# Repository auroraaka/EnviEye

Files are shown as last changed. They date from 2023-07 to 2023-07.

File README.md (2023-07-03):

# EnviEye: Air Pollution Monitoring System
A novel, cost-effective, and temperature/humidity drift resilient air pollution monitor for detecting CO2, CO, CH4, NOx, NH3, H2S, and VOCs. Building an open-source database of minute-by-minute air quality in high-risk locations across Massachusetts. In partnership with the MassDEP and sponsored by EPA Enhanced Air Quality Monitoring for Communities Grant.

## Quick Links
- [Sensor Map Database](https://www.environa.org/envieye): location marker database of ThingSpeak channels displaying active data from live EnviEye air pollution monitors
- [Build Guide](https://docs.google.com/presentation/d/e/2PACX-1vTb9qzZoU7ihO3saF2nRVf8Kc_sK2KtpKpaAT560-QxsJg3QxZHz59rv6SrPiSbV5mgcdfRNgG8oTTH/pub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): step-by-step instructional manual slideshow including required components and tools
- [Technical Documentation](https://www.environa.org/_files/ugd/a23aa6_806df408c55a414ab66d8ea2d8b6d26c.pdf): full engineering-based analysis of sensor theory, technology, limitations, and impact
- [IEEE Sensors Paper](https://ieeexplore.ieee.org/document/9812483): discusses how to improve the accuracy of MOS gas sensors in ambient conditions
- [Patent](https://patents.google.com/patent/US20230112016A1/en): establishes intellectual property over sensor innovations

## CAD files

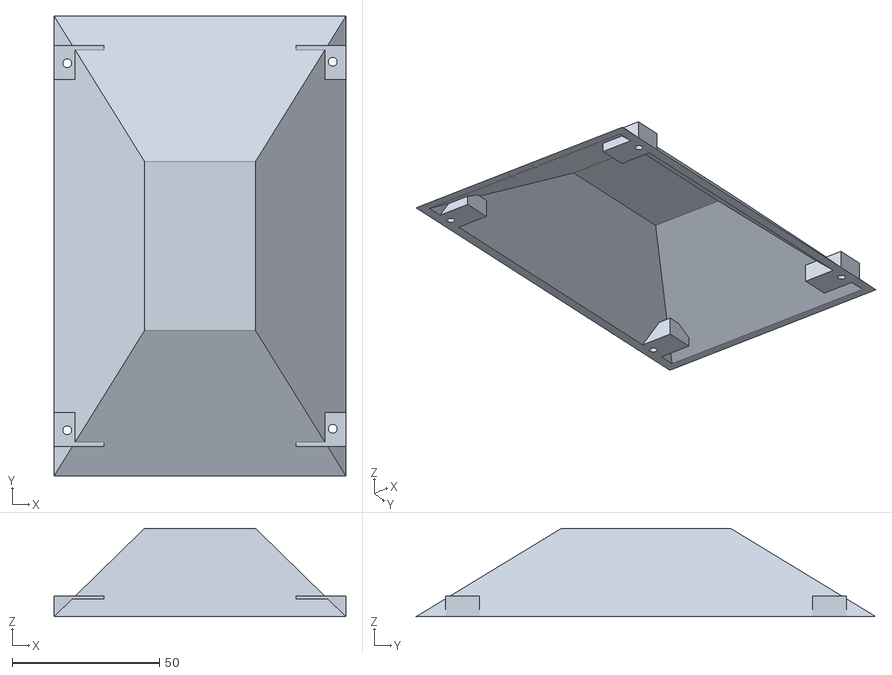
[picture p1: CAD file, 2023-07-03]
Hardware/Enclosure/Roof.obj
99.0 x 156.0 x 30.0

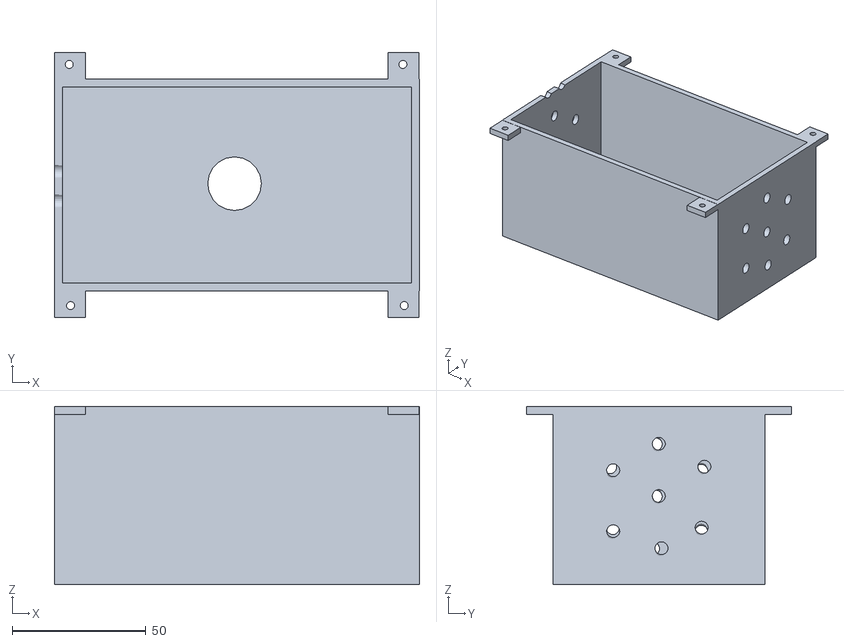
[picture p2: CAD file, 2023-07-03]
Hardware/Enclosure/Base.obj
136.2 x 99.0 x 66.5

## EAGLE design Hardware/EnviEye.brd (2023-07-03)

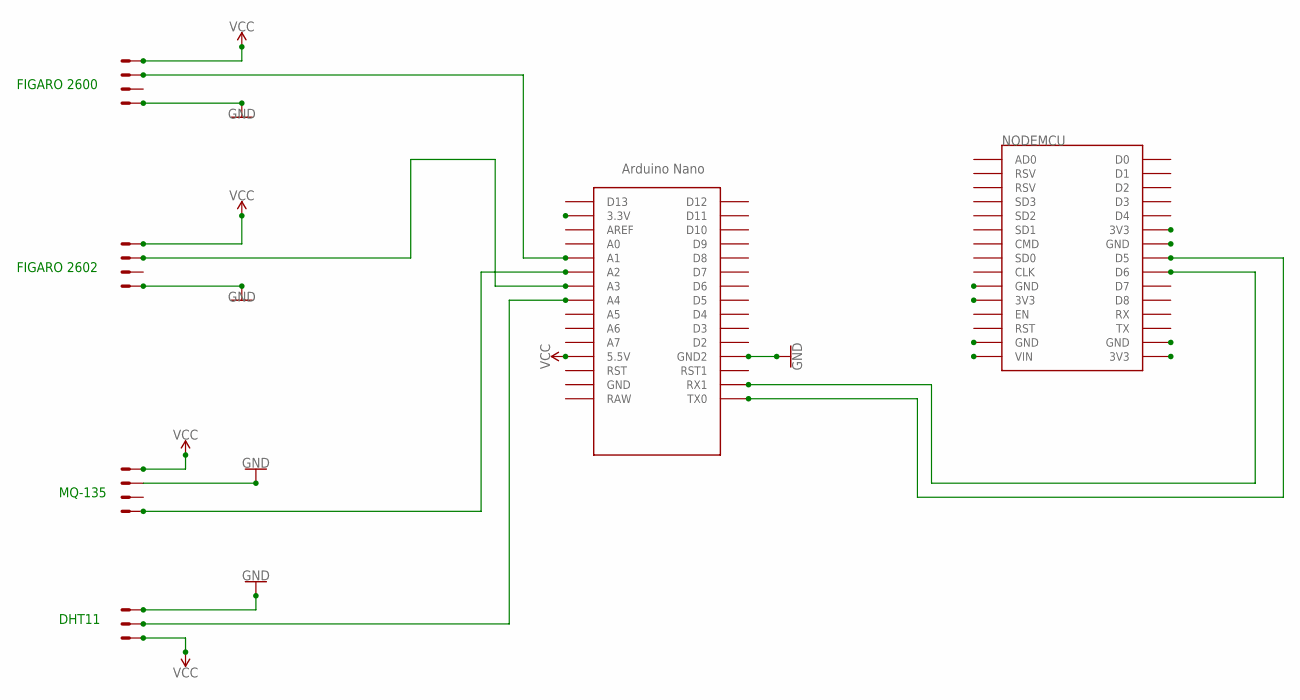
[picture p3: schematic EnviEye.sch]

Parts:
DHT11: 22-23-2031
FIGARO2600, FIGARO2602: 22-23-2041
MQ-135: 22-23-2041
NODEMCU: ESP12E_DEVKIT
U$1: NANO

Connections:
GND: DHT11.3, FIGARO2600.4, FIGARO2602.4, MQ-135.2, U$1.GND1 (GND2)
unnamed: FIGARO2600.2, U$1.A3
unnamed: FIGARO2602.2, U$1.A1
unnamed: NODEMCU.D6, U$1.RX1
unnamed: NODEMCU.D5, U$1.TX0
unnamed: DHT11.2, U$1.A4
unnamed: MQ-135.4, U$1.A2
VCC: DHT11.1, FIGARO2600.1, FIGARO2602.1, MQ-135.1, U$1.5V (5.5V)

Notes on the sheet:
MQ-135
DHT11
FIGARO 2602
FIGARO 2600

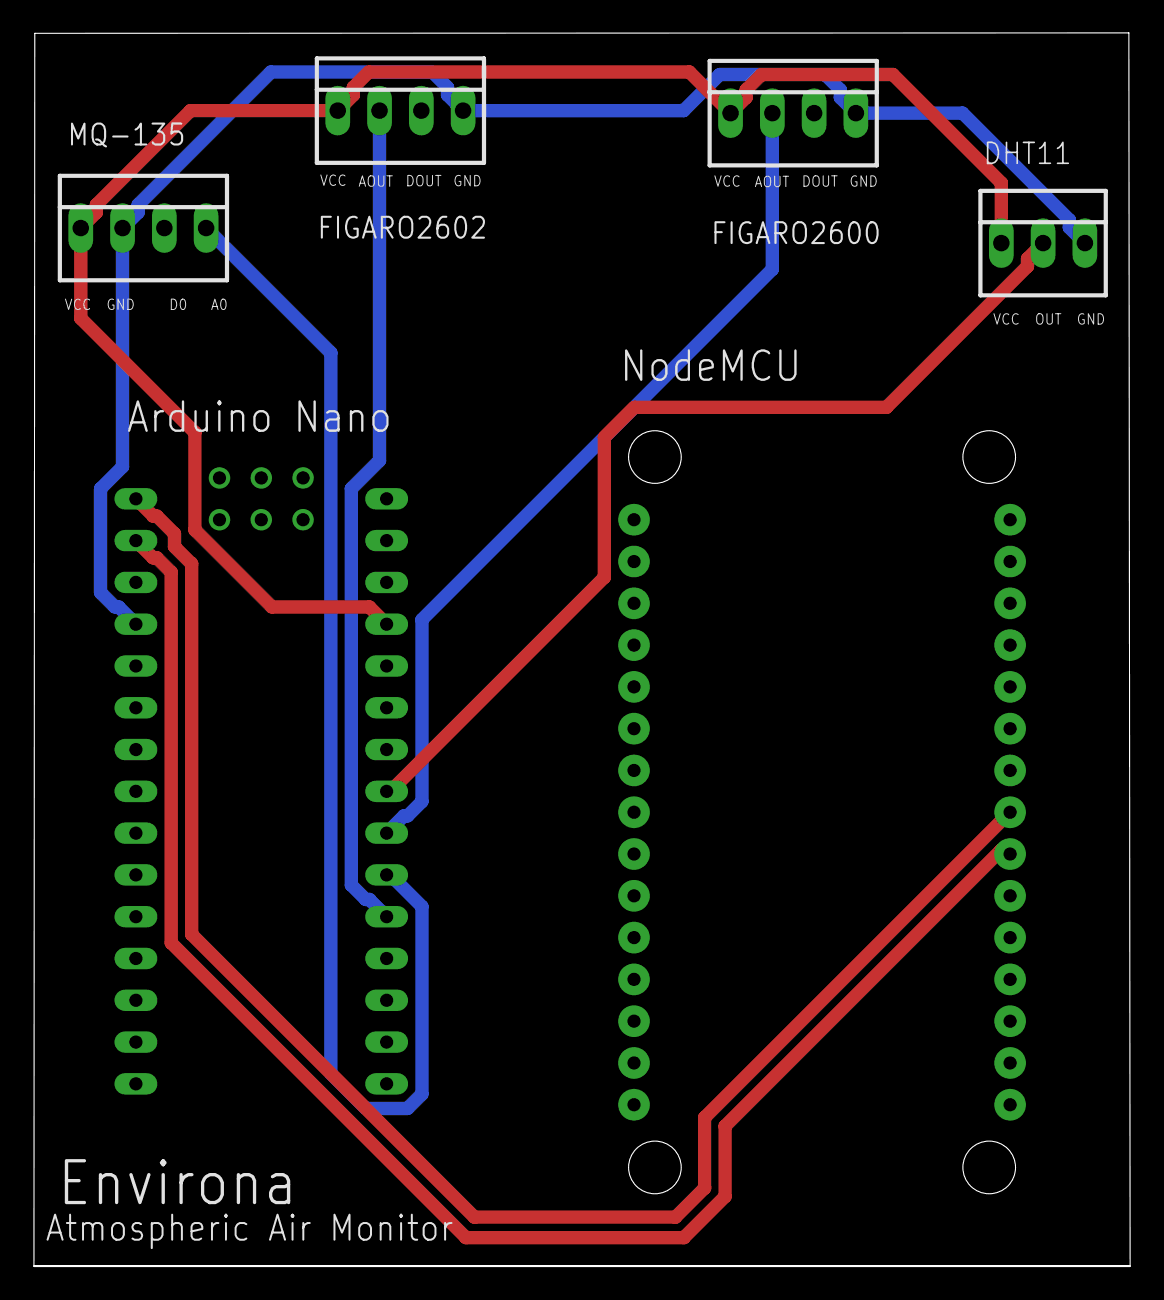
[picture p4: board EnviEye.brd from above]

Board: 2 copper layers, 66.6 x 75.0 mm, 6 parts (0 on the bottom side), 8 nets.

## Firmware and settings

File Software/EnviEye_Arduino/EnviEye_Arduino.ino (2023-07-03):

/* 
Atmospheric Air Analyzer
Environa
Akarsh Aurora
11/13/20
*/
 
#include <ArduinoJson.h>
#include <DHT.h>

// Gas Sensor Pins
#define F2600 A1
#define MQ135 A2
#define F2602 A3
#define DHTPIN A4
    
// 2600 Gases
float A_CO = 1.144997421;
float B_CO = -0.21687423;

float A_CH4 = 1.05777824;
float B_CH4 = -0.0795645;

// 2602 Gases
float A_NH3 = 0.92372844;
float B_NH3 = -0.291578925;

float A_H2S = 0.38881036;
float B_H2S = -0.35010059;

float A_VOC = 0.3220722;
float B_VOC = -0.6007520;

// MQ-135 Gases
float A_CO2 = 112.89808; 
float B_CO2 = -2.868463517;  

float A_NOx = 34.69756084;  
float B_NOx = -3.422829698; 

// DHT Temperature and Humidity
#define DHTTYPE DHT11
DHT dht(DHTPIN, DHTTYPE, 6);
float H, T, F;

void setup() {
  pinMode(13, OUTPUT);
  Serial.begin(9600);
  dht.begin();
}

void loop() {

  // Setting Pin 13 to GND
  digitalWrite(13, LOW);
  
  // DHT11 Temperature and Humidity Measurements
  DetectTemperatureHumidity ();
  
  // Figaro 2600 Gas Concentrations (CO and CH4)
  float ratio_F2600 = CalculateRatio(F2600, CalculateK_2600(), 400);
  float ppm_CO = A_CO * pow(ratio_F2600, B_CO) * 0.1;
  float ppm_CH4 = A_CH4 * pow(ratio_F2600, B_CH4) * 0.1;

  // MQ-135 Gas Concentrations (CO2 and NOx)
  float ratio_MQ135 = CalculateRatio(MQ135, CalculateK_MQ135(), 24);
  float ppm_CO2 = analogRead(MQ135) + 325;
  float ppm_NOx = A_NOx * pow(ratio_MQ135, B_NOx) * 10;

  // Figaro 2602 Gas Concentrations (VOC, H2S, and NH3)
  float ratio_F2602 = CalculateRatio(F2602, CalculateK_2602(), 225);
  float ppm_VOC = A_VOC * pow(ratio_F2602, B_VOC) * 0.001 * 1000000/2;
  float ppm_H2S = A_H2S * pow(ratio_F2602, B_H2S) * 0.001;
  float ppm_NH3 = A_NH3 * pow(ratio_F2602, B_NH3) * 0.001;  
  
  // Upload data to ThingSpeak Channel
  DynamicJsonBuffer jBuffer; 
  JsonObject& root = jBuffer.createObject();

  root["CO2"] = ppm_CO2;
  root["CO"] = ppm_CO;
  root["CH4"] = ppm_CH4;
  root["NOx"] = ppm_NOx;
  root["NH3"] = ppm_NH3;
  root["H2S"] = ppm_H2S;
  root["VOC"] = ppm_VOC;
  root["Temperature"] = T;
  root["Humidity"] = H;
   
  root.prettyPrintTo(Serial);
  Serial.println("");

  // ThingSpeak Delay
  delay(10000);
}

// Calculate Rs/Ro
float CalculateRatio (int SensorPin, float K, float Rs0){
  float VRL;
  float Rs;
  float RL = 10;
  float Ro;
  float ratio;
  VRL = analogRead(SensorPin)*(5.0/1023.0);
  Rs = (5.0/VRL - 1)*RL;
  Ro = Rs0/K;
  ratio = Rs/Ro;
  return ratio;
}


float CalculateK_2600 (){
  float K_2600;
  K_2600 = (-6.073E-7)*pow(T, 4) + (4.218E-5)*pow(T, 3) + (-8.710E-5)*pow(T, 2) + (-0.055)*T + (1.901);
  return K_2600;
}

float CalculateK_2602 (){
  float K_2602;
  K_2602 = (-1.519E-7)*pow(T, 4) + (1.796E-5)*pow(T, 3) + (-5.415E-4)*pow(T, 2) + (-0.024)*T + (1.585);
  return K_2602;
}

float CalculateK_MQ135 (){
  float K_MQ135;
  K_MQ135 = (-1.028E-7)*pow(T, 4) + (3.911E-6)*pow(T, 3) + (4.215E-4)*pow(T, 2) + (-0.027)*T + (1.318);
  return K_MQ135; 
}

float DetectTemperatureHumidity (){
  H = dht.readHumidity();
  T = dht.readTemperature();
  F = dht.readTemperature(true);
  if (isnan(H) || isnan(T) || isnan(F)) {
    Serial.println("Failed to read from DHT sensor!");
    return;
  }
}

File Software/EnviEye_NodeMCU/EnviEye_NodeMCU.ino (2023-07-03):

#include <ESP8266WiFi.h>
#include <ESP8266HTTPClient.h>
#include <ArduinoJson.h>
#include <SoftwareSerial.h>
#include "ThingSpeak.h"

SoftwareSerial mySerial(D5, D6);
WiFiClient client; // Creating WiFiClient Object

//ThingSpeak Channel's API Keys
unsigned long myChannelNumber = // Enter ThingSpeak Channel ID
const char * myWriteAPIKey = // Enter ThingSpeak Channel Key

// Add WIFI credentials here

char* WIFI_SSID[] = {"WIFI_SSID_1", "WIFI_SSID_2", "WIFI_SSID_3"}; // List WIFI SSIDs
char* WIFI_PASSWORD[] = {"WIFI_PASSWORD_1", "WIFI_PASSWORD_2", "WIFI_PASSWORD_3"}; // List WIFI Passwords

void WIFI_SEARCH() {
  int SSID_COUNT = 0;
  do {
    Serial.println("Attempting connection to WIFI network: " + String(WIFI_SSID[SSID_COUNT]));
    WiFi.begin(WIFI_SSID[SSID_COUNT], WIFI_PASSWORD[SSID_COUNT]);
    int WIFI_TIMEOUT_COUNT = 0;
    while (WiFi.status() != WL_CONNECTED && WIFI_TIMEOUT_COUNT < 100) { 
      delay(100);
      Serial.println(".");
      ++WIFI_TIMEOUT_COUNT;
    }
    if (WiFi.status() == WL_CONNECTED) {
      Serial.println("Connected to WIFI network: " + String(WIFI_SSID[SSID_COUNT]));
      Serial.println(WiFi.localIP());
    }
    ++SSID_COUNT;
  }
  while (WiFi.status() != WL_CONNECTED);
}

void setup() {
  Serial.begin(9600);
  mySerial.begin(9600);
  WIFI_SEARCH();
  ThingSpeak.begin(client);
}

void loop() {

  // Check WiFi status
  while (mySerial.available())
  {
    const size_t capacity = JSON_OBJECT_SIZE(8) + 100;
    DynamicJsonBuffer jsonBuffer(capacity);
    JsonObject& root = jsonBuffer.parseObject(mySerial);
    if (!root.success()) {
      Serial.println("parseObject() failed");
      return;
    }

    float CO2 = root["CO2"];
    float CO = root["CO"];
    float CH4 = root["CH4"];
    float NOx = root["NOx"];
    float NH3 = root["NH3"];
    float H2S = root["H2S"];
    float VOC = root["VOC"];
    float Temperature = root["Temperature"];

    Serial.print(CO2, D5);  Serial.print(",");
    Serial.print(CO, D5);  Serial.print(",");
    Serial.print(CH4, D5);  Serial.print(",");
    Serial.print(NOx, D5);  Serial.print(",");
    Serial.print(NH3, D5);  Serial.print(",");
    Serial.print(H2S, D5); Serial.print(",");
    Serial.print(VOC, D5); Serial.print(",");
    Serial.println(Temperature, D5); 
    
    // Send gas concentration data to ThingSpeak channel
    ThingSpeak.setField(1, CO2);
    ThingSpeak.setField(2, CO);
    ThingSpeak.setField(3, CH4);
    ThingSpeak.setField(4, NOx);
    ThingSpeak.setField(5, NH3);
    ThingSpeak.setField(6, H2S);
    ThingSpeak.setField(7, VOC);
    ThingSpeak.setField(8, Temperature);
    ThingSpeak.writeFields(myChannelNumber, myWriteAPIKey);
  }
}

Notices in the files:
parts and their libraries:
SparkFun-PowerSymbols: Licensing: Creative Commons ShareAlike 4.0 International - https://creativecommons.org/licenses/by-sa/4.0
